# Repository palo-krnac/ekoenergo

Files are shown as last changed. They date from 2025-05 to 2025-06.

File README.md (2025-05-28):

# ekoenergo – Solar Water Heating Inverter

**ekoenergo** is an open source project of a solar inverter for heating domestic hot water. It can be used to power a boiler coil and connect electric resistance heating coils and radiators.

This inverter is specifically designed to optimize the use of photovoltaic (PV) panels for powering a standard electric heating element in a domestic hot water (DHW) storage tank (boiler). It converts direct current (DC) from PV panels into alternating current (AC) with a 50 Hz rectangular waveform and a variable duty cycle ranging from approximately **3% to 98%**.

In automatic mode, the inverter continuously measures **voltage and current** to calculate the output power of the PV panels. It dynamically adjusts the duty cycle to maintain the **Maximum Power Point Tracking (MPPT)**, ensuring optimal energy extraction.

Without this feature, a fixed full-duty load on the panels — especially in **low-light conditions** — would cause voltage to drop, resulting in minimal power output. Thanks to MPPT, the inverter excels even in weak or fluctuating sunlight, such as during **early mornings, evenings, cloudy skies, or partial shading**.

> **Example:**  
> If the duty cycle is manually set to 100% under weak sunlight, you might get only **300 W** from a nominal **750 W** PV system. With MPPT, the inverter adjusts the load to extract significantly more energy.

---

## Installation and Usage Guidelines

- Place the inverter as **close to the boiler** as possible.
- Connect **only resistive loads** to the output terminals (e.g., heating element, immersion heater, standard boiler **without** electronics or contactors).
- Do **not** connect the output to:
  - Ground
  - Other inverters
  - External voltage sources

---

## Technical Specifications

| Parameter | Value |
|---|---|
| **Max PV input voltage (open circuit)** | 400 V DC |
| **Continuous output current** | 8–9 A |
| **Maximum output current** | 10 A |
| **Maximum output power** | approx. 2800 W |
| **Recommended PV array** | 8 panels, 260–280 Wp each |
| **Recommended heating element** | 2–3 kW / 230 V |
| **Minimum resistive load** | approx. 15 Ω |

---

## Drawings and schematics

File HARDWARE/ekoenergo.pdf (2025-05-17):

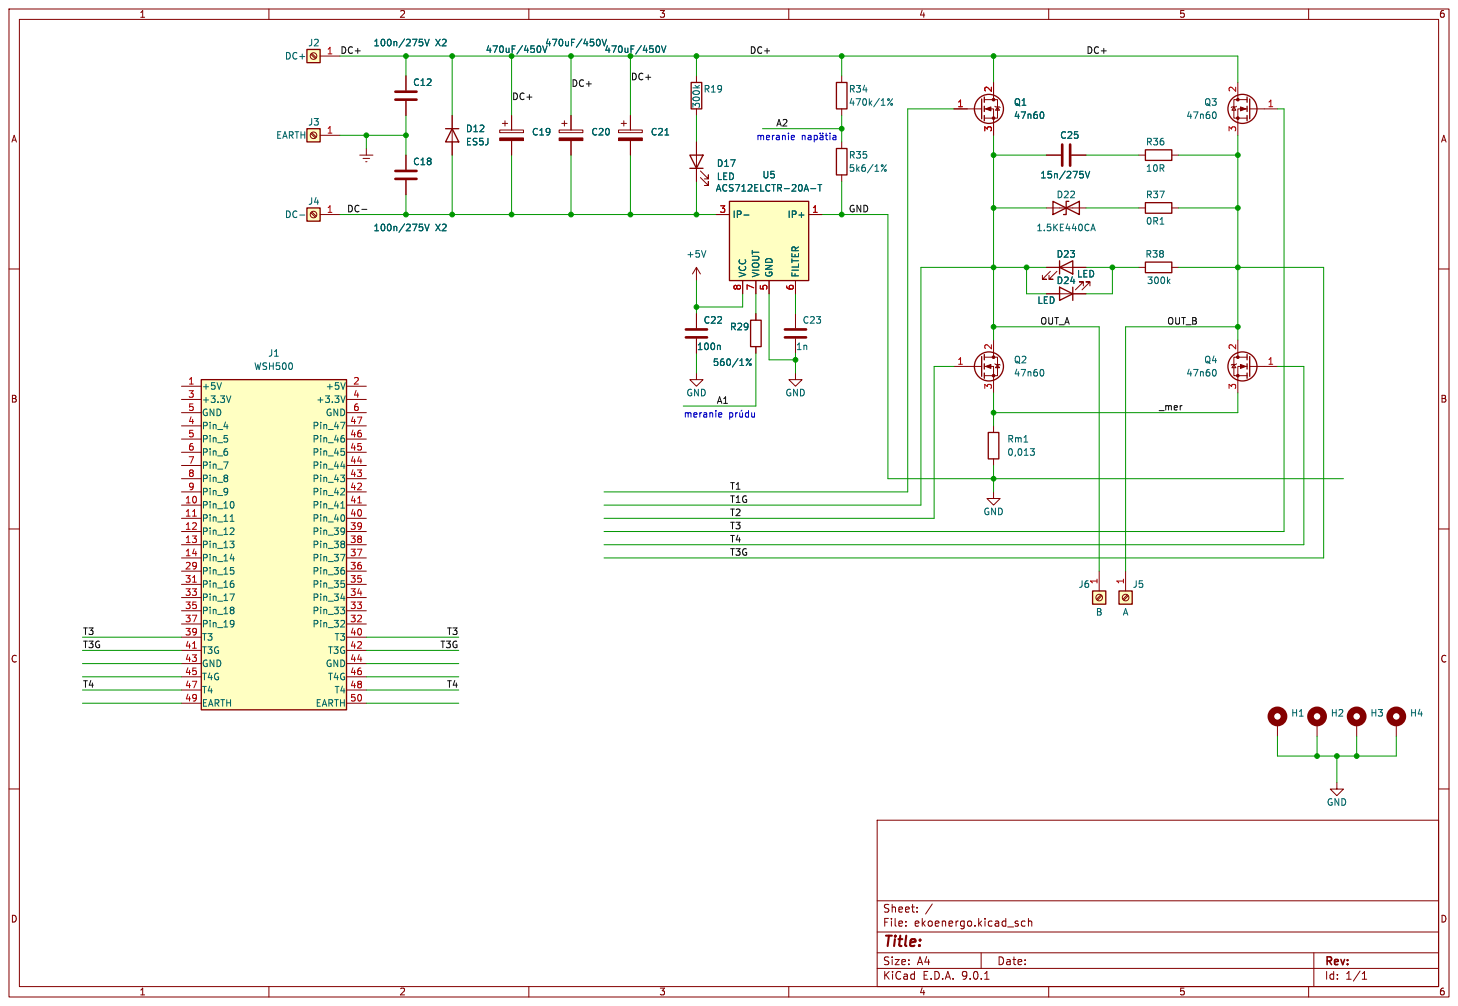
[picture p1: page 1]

Id: 1/1 Title: File: ekoenergo.kicad_sch Sheet: /

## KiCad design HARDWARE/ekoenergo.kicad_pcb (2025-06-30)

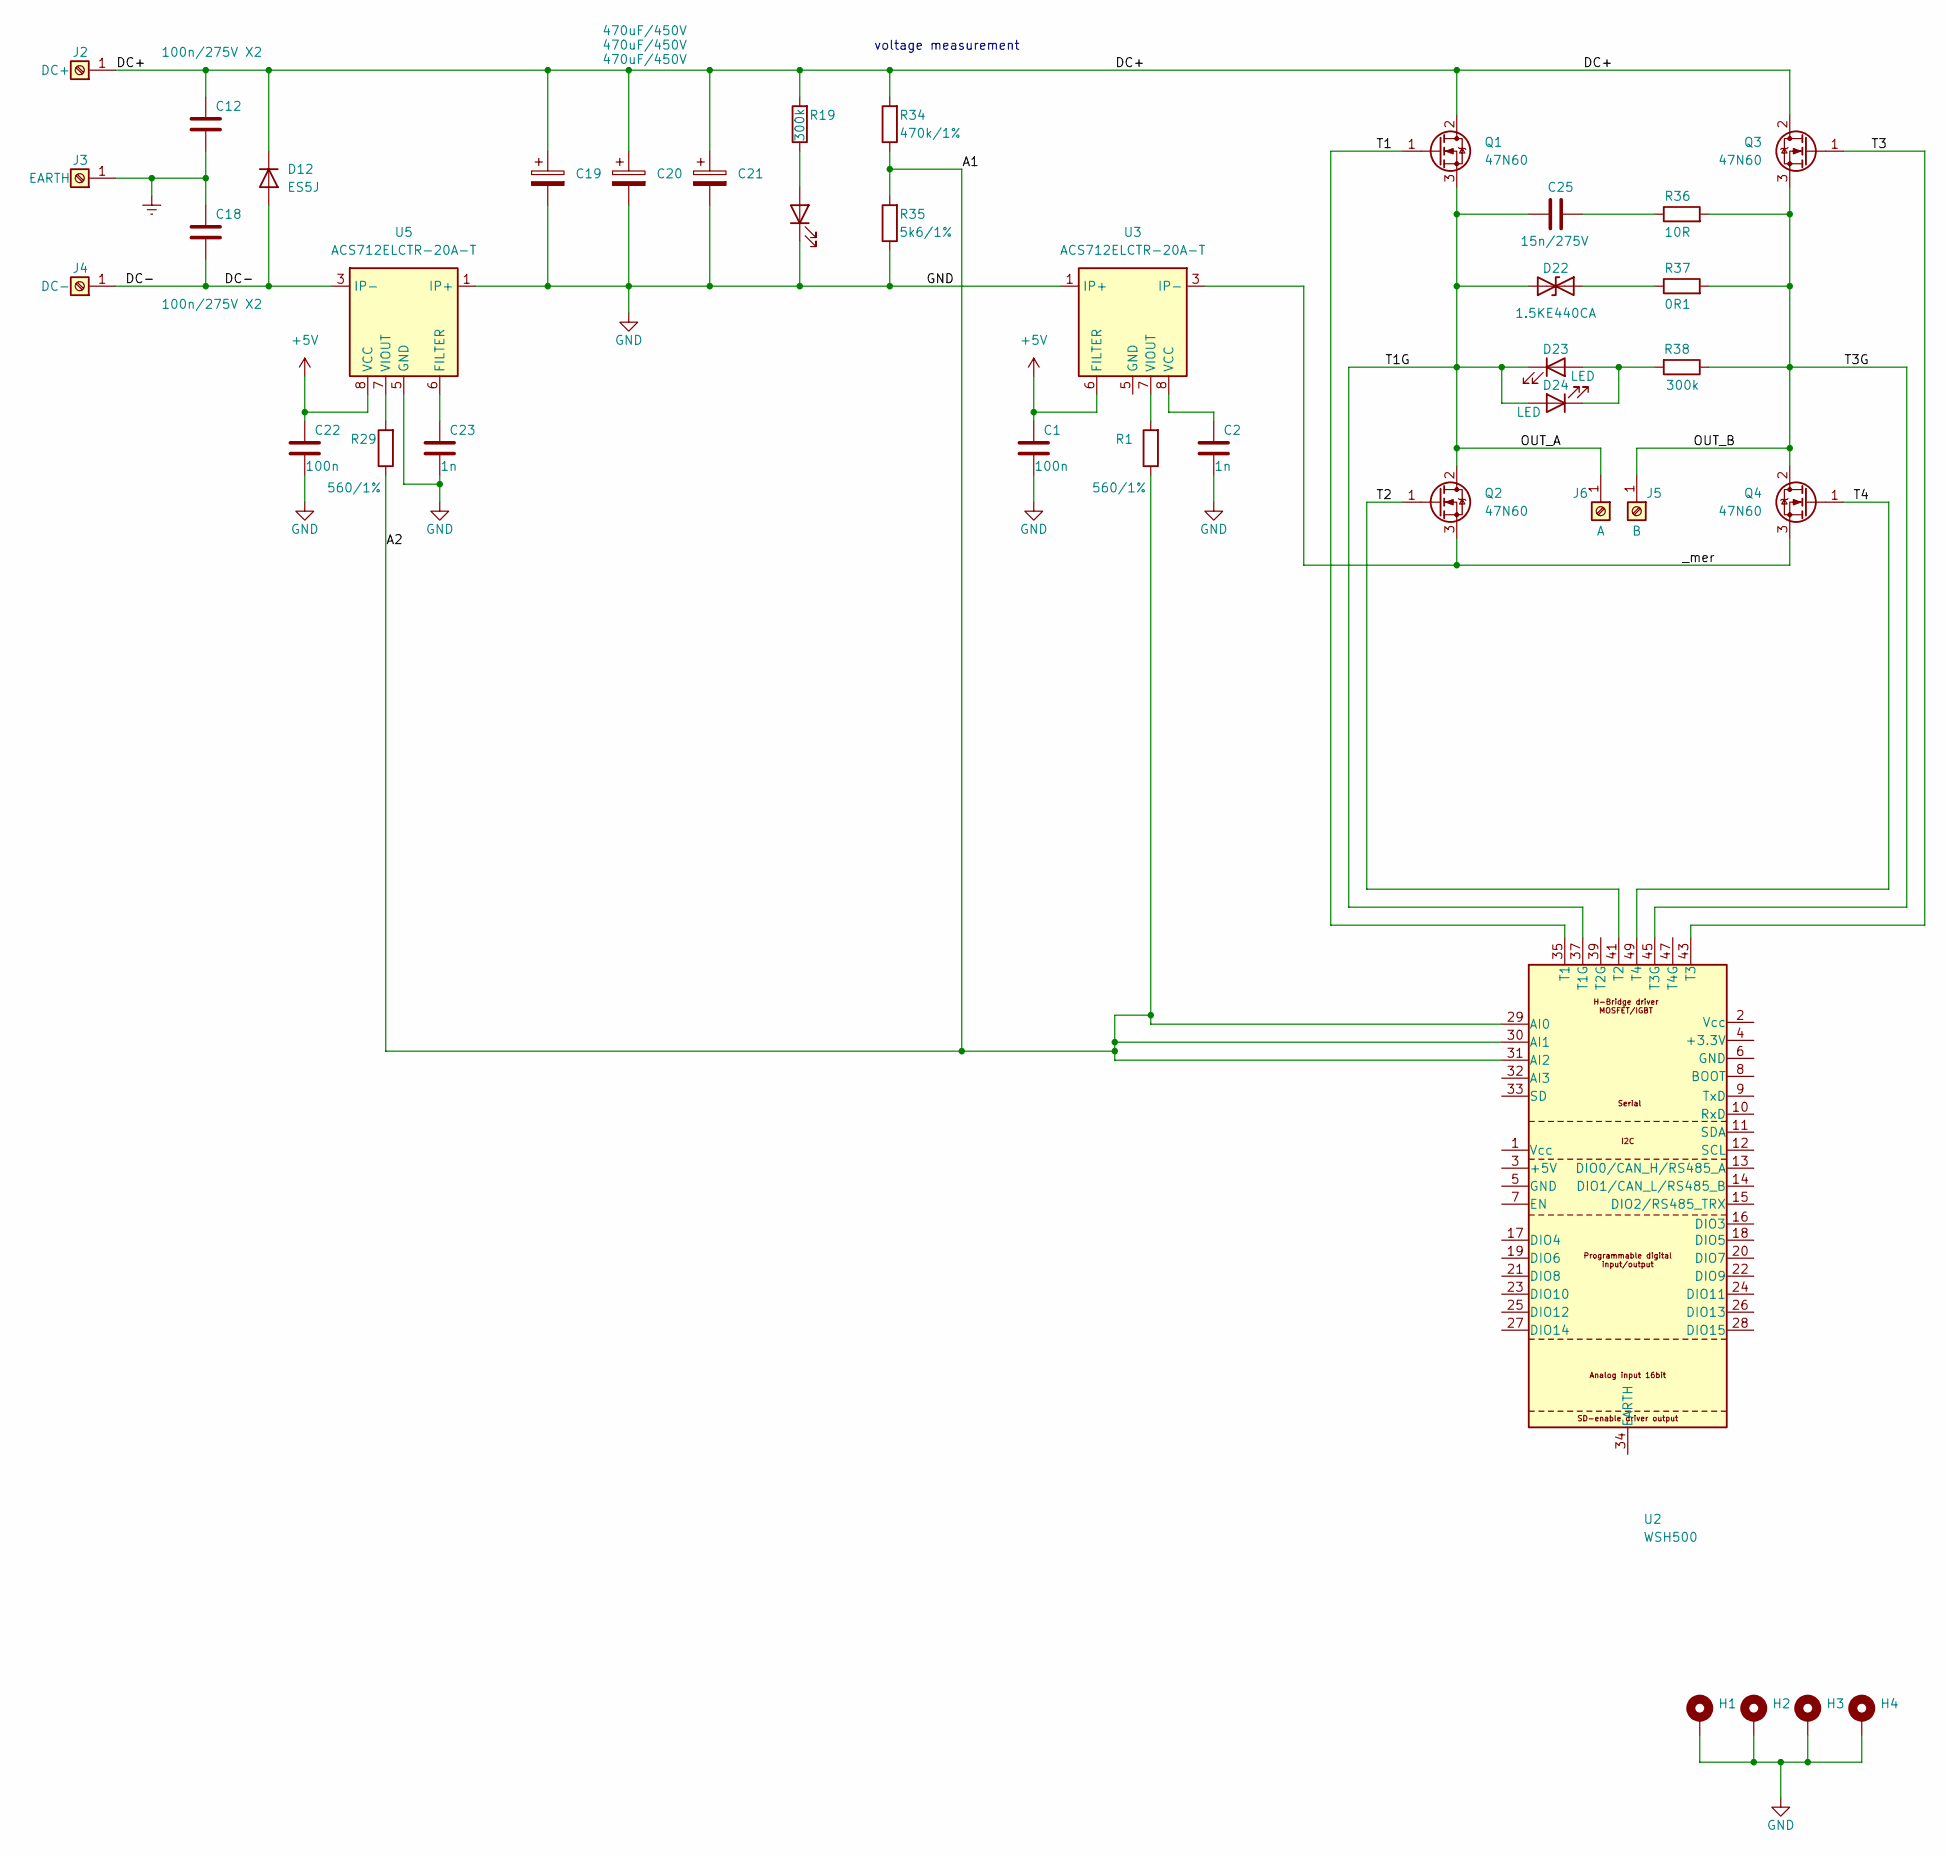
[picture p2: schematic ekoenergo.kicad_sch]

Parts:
C1, C22: 100n; C_0805_2012Metric
C2, C23: 1n; C_0805_2012Metric
C12, C18: 100n/275V X2; C_Rect_L13.0mm_W8.0mm_P10.00mm_FKS3_FKP3_MKS4
C19, C20, C21: 470uF/450V; WE_861011486024
C25: 15n/275V
D12: ES5J; D_SMB
D17, D23, D24: LED; LED_0805_2012Metric
D22: 1.5KE440CA; D_DO-201AE_P15.24mm_Horizontal
H1, H2, H3, H4: 3,2; MountingHole_3.2mm_M3_Pad_Via
J2: DC+; KEYS_7796
J3: EARTH; KEYS_7796
J4: DC-; KEYS_7796
J5: B; KEYS_7796
J6: A; KEYS_7796
Q1, Q2, Q3, Q4: 47N60; TO-247-3_Horizontal_TabDown_Cut
R1, R29: 560/1%; R_0805_2012Metric
R19, R38: 300k; R_0805_2012Metric
R34: 470k/1%; R_0805_2012Metric
R35: 5k6/1%; R_0805_2012Metric
R36: 10R
R37: 0R1
U2: WSH500; WSH500_SMD
U3, U5: ACS712ELCTR-20A-T; SOIC-8_3.9x4.9mm_P1.27mm

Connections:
+5V: C1.1, C22.1, U3.6 (FILTER), U5.8 (VCC)
/A1: R1.1, R29.1, R34.1, R35.2, U2.29 (AI0), U2.30 (AI1), U2.31 (AI2)
/DC+: C12.1, C19.1, C20.1, C21.1, D12.1, J2.1, Q1.2 (D), Q3.2 (D), R19.2, R34.2
/DC-: C18.2, D12.2, J4.1, U5.3 (IP-), U5.4 (IP-)
/OUT_A: C25.1, D22.1 (A1), D23.1 (K), D24.2 (A), J6.1, Q1.3 (S), Q2.2 (D), U2.37 (T1G), U2.38 (T1G)
/OUT_B: J5.1, Q3.3 (S), Q4.2 (D), R36.2, R37.2, R38.1, U2.45 (T3G), U2.46 (T3G)
/T1: Q1.1 (G), U2.35 (T1), U2.36 (T1)
/T2: Q2.1 (G), U2.41 (T2), U2.42 (T2)
/T3: Q3.1 (G), U2.43 (T3), U2.44 (T3)
/T4: Q4.1 (G), U2.49 (T4), U2.50 (T4)
/_mer: Q2.3 (S), Q4.3 (S), U3.3 (IP-), U3.4 (IP-)
Earth: C12.2, C18.1, J3.1
GND: C1.2, C2.2, C19.2, C20.2, C21.2, C22.2, C23.2, D17.1 (K), H1.1, H2.1, H3.1, H4.1, R35.1, U3.1 (IP+), U3.2 (IP+), U5.1 (IP+), U5.2 (IP+), U5.5 (GND)
unnamed: C25.2, R36.1
unnamed: D17.2 (A), R19.1
unnamed: D22.2 (A2), R37.1
unnamed: D23.2 (A), D24.1 (K), R38.2
unnamed: U2.39 (T2G), U2.40 (T2G)
unnamed: U2.47 (T4G), U2.48 (T4G)
unnamed: C2.1, U3.8 (VCC)
unnamed: R1.2, U3.7 (VIOUT)
unnamed: C23.1, U5.6 (FILTER)
unnamed: R29.2, U5.7 (VIOUT)

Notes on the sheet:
voltage measurement

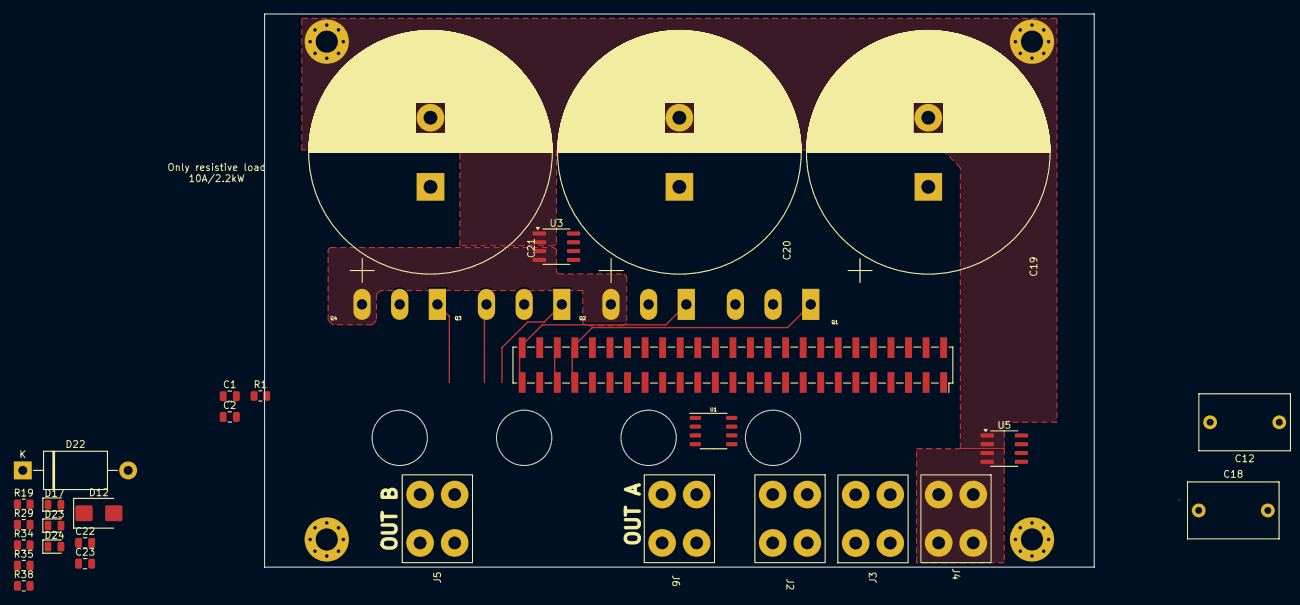
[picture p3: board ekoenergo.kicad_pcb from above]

Board: 4 copper layers, 120.0 x 80.0 mm, 37 parts (0 on the bottom side), 21 nets.

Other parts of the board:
U1: WS3081; SOP-8_3.9x4.9mm_P1.27mm
